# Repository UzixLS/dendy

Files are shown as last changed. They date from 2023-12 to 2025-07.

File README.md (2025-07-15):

## Dendy
Yet another Dendy (Famicom) clone - 8-bit home video game console

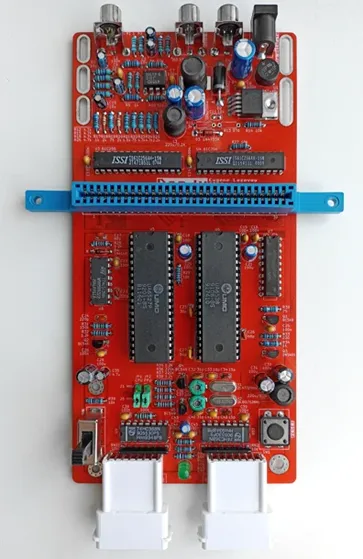
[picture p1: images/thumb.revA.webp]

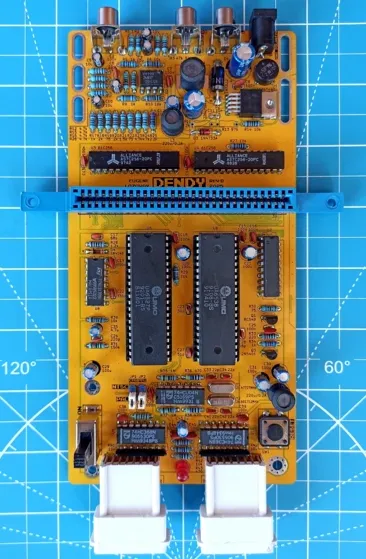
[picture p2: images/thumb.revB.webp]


[(more random photos there)](https://cloud.err200.net/index.php/s/73TR85tYZkMm8Ax?path=%2Fdendy)

- PCB optimized for NewGame's case
- Almost all components is DIP (THT)
- 9-12V DC power supply with any polarity
- Step-down switching regulator
- PNP+NPN transistors-based video amplifier
- OpAmp-based audio mixer/amplifier
- Two switchable quartz crystals (PAL+NTSC)

### Changelog & current status
* Rev.A - first release. Please note the [errata](pcb/rev.A/ERRATA.txt)
* Rev.B:
    - Reworked crystal generator circuit
    - Tuned pcb's dimensions and holes placement for better compatibility with enclosures
    - Various minor changes and improvements
* Rev.B1:
    - Power switch moved up to 0.5mm
    - Various minor changes and improvements

### Credits
I want to express my appreciation to the
 - megawalkman
 - HardWareMan
 - lm2000
 - HotPixel

authors of the following projects, which served as inspiration and as reference for my development:

- https://www.emu-land.net/forum/index.php/topic,75737.0.html - Dendy Classic/Junior Steepler Remake
- https://www.emu-land.net/forum/index.php/topic,78815.0.html - Dendy Junior Remastered
- https://github.com/mleonid2000/dendy_junior_remastered - Dendy Junior Remastered
- https://github.com/HotPixelChannel/Candy_8bit - Candy 8bit system

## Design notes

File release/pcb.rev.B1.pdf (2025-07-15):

1 | 2 | 3 | 4 | 5 | 6 | 7 | 8
1 | 2 | 3 | 4 | 5 | 6 | 7 | 8

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
F Date: 2025-06-08 KiCad | E.D.A. 8.0.9 Size: A3 | Rev: | B1

# Id: 1/1 Title: Dendy

File: dendy.kicad_sch Sheet: / Eugene | Lozovoy Based | on original | Famicom, | HardWareMan, megawalkman, | lm2000, | HotPixel schematics Famicom/NES | clone

GND

+5V

+5VA_1 | R1

1

C30

100u | C29
| 100u

1

- 2 +
3 | V⁻ 4 V⁺ 8 | U2A
4558D GNDA | R2

1 Y1
21.47727MHz | C1
10u | GNDA R3 47k

+5V

13 | 12 U11F
74HCU04 | GNDA
O2 | 10 O1 | 11 O0 | 12 A1 13 | A0 14 | E
15 | O3 | 9 U8B
74LS139 | R36 470 GND 14 VCC ²⁸ A14 1 | A0 10 | Q0 11 Q1 12 Q2 13 Q3 15 Q4 16 Q5 17 Q6 18 Q7 19 A12 2 | ~{CS}20 A10 21 | ~{OE}22 A11 23 A9 24 A8 25 A13 26 | ~{WE}27 A7 3 | A6 4 | A5 5 | A4 6 | A3 7 | A2 8 | A1 9 | U3

# 61C256 SRAM

6264, 62128, | 62256, | AS7C256, W24257AK

R7 510

GND GND

11 | 10 U11E

74HCU04 GND

GND | GND 14 VCC ²⁸ A14 1 | A0 10 | Q0 11 Q1 12 Q2 13 Q3 15 Q4 16 Q5 17 Q6 18 Q7 19 A12 2 | ~{CS}20 A10 21 | ~{OE}22 A11 23 A9 24 A8 25 A13 26 | ~{WE}27 A7 3 | A6 4 | A5 5 | A4 6 | A3 7 | A2 8 | A1 9 | U4

# 61C256 SRAM

6264, 62128, | 62256, | AS7C256

R14
10k 1
2

3

SW2

R27 10k

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
100n

GND

C24

220p ¹
2

3

JP1

GND

1

2

3

J4 DC IN

GND | VCC ¹⁶ GND

8 U8C
74LS139

GND

GND

GND GND

C16

100n | C15

100n C14

100n

+5V | GND GND

C19

100n

-1

2 +

3

4 D1

+5V

1

2

J1RCJ-014

C22

330p | 1

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
J5 FC 60 pin cartridge | slot +5V
F1 | 1A
OE 1 | GND 10
LE 11 | O4 12 D4 13 D5 14 | O5 15 O6 16 D6 17 D7 18 | O7 19 O0 | 2 VCC ²⁰ D0 3 | D1 4 | O1 | 5 O2 | 6 D2 7 | D3 8 | O3 | 9 U7
74LS373 GND

+5V R28

1.2k D4

1N4148 | GND

C4

470u/25V

+5V C23

30p | C17
68p | C26

68p GND GND

R29 | 10k GND
+5V | GND GND GND | SND1 | 1 A6 10 A7 11 A8 12 A9 13 A10 14 A11 15 A12 16 A13 17 A14 18 A15 19 SND2 | 2 GND 20 D7 21 D6 22 D5 23 D4 24 D3 25 D2 26 D1 27 D0 28 CLK 29 ~{RST} 3 | TST 30 | M2 31 ~{IRQ} 32 ~{NMI} 33 | R/~{W} 34 ~{OE2} 35 ~{OE1} 36 OUT2 37 OUT1 38 OUT0 39 | A0 | 4 VCC ⁴⁰ | A1 | 5 A2 | 6 A3 | 7 A4 | 8 A5 | 9 U5 UA6527P CPU
HA6527P, TA-03NP, | MG-P-501 | +5V GND R¹¹ 3kL1 | C11

10n 1

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
J9 DB15_Male

Joypad 2 ¹⁰k R⁴² 10k R⁴¹ C43

1u GND

R/~{W} 1 | A2 10 A1 11 A0 12 ~{CS} 13 EXT0 14 EXT1 15 EXT2 16 EXT3 17 CLK 18 ~{INT} 19 D0 2 | GND 20 | VOUT 21 ~{RST} 22 | ~{WR}23 ~{RD}24 PA13 25 PA12 26 PA11 27 PA10 28 PA9 29 D1 3 | PA8 30 ALE 39 D2 4 | VCC ⁴⁰ D3 5 | D4 6 | D5 7 | D6 8 | D7 9 | PAD7 31 PAD6 32 PAD5 33 PAD4 34 PAD3 35 PAD2 36 PAD1 37 PAD0 38 U6 UA6538 PPU
HA6538, TA-02NP, | MG-P-502

+5V

+5V | 1
2
3
4
5
6

J7

Joypad 2 GND GND

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
J8 DB15_Male

# Joypad 1 1

2
3
4
5

J6

Joypad 1 | C34
22p | R35
1M

+5V

1

2

J2RCJ-014 GNDA | GNDA GND
+5V | 1

2

J3RCJ-014 C42

22p

+5V 1

8

7

6

5

4

3

2 RN1
10k

+5VA_1 R40

100k OEa | 1
I4 | 10 O5b 11 | I5 | 12 O6b 13 | I6 | 14 OEb | 15 VCC ¹⁶
I1 | 2 O1a 3
I2 | 4 O2a 5
I3 | 6 O3a 7 | GND

# 8 O4a 9 U9

74HC368 | 1

8

7

6

5

4

3

2 RN2

# 10k GND

+5V

C44

100n +5V

L2

47uH/2A | R¹³ 1k | C9
| | 220u/16V

L3

220u/0.2A | GNDA C12
100u | C7
100n | GNDA D3
1N4733A GND OEa | 1
I4 | 10 O5b 11 | I5 | 12 O6b 13 | I6 | 14 OEb | 15 VCC ¹⁶
I1 | 2 O1a 3
I2 | 4 O2a 5
I3 | 6 O3a 7 | GND

# 8 O4a 9 U10

74HC368 +5V | D2

1N5822

+5V | GND

+5V

C3
10u R4 47k

+5VA_1R8 510

GND

JP3 | C45
100n | R6

10k +5VA_1 R12 4.7k

C31

100u | C25
100n | SW¹
GND | GND

C28

100n ¹
2
3 Q3
2N5401 VIN 1 | OUT 2 GND

## 3 FB 4 ~{ON}/OFF 5 U1

LM2596T-ADJ LM2596T-5.0 | VCC ¹⁴ GND

7 U11G

74HCU04 +5V

+5V R9
1k +5VA_2

C10

10u +5VA_1 R34 1k GNDA | GNDA

E

1 | A0 2 | A1 3 | O0 | 4 O1 | 5 O2 | 6 O3 | 7 U8A
74LS139

GNDA

+5V

L4

220u/0.2A

# R26 4.7k R16 4.7k C5

10u 3 | 4 U11B

74HCU04 Y2

26.601712MHz | R5
1k GNDA R15 4.7k | HOLE8 HOLE6 1 | 2 U11A

74HCU04 R38 470

HOLE7 C35

4.7u GND

R39 10k

R37
1M

C33

22p GND

HOLE3 HOLE5 HOLE1 C41

22p | +5V GND

D5
LED
9 | 8 U11D
74HCU04 5 | 6 U11C
74HCU04 GND | R⁴³ 470
+5V | GND GND
+5VA_2 R33 270 | 1

2
3 Q1 BC549BR30
75 | GND
R25 2.2k 75R22 GND | 75R19 R31 150k | GNDA | GND

HOLE2 HOLE4 R24
4.7k C20

100u C21

100u

R18

2k R21
1.5k C38
100n | C39
| 100n

R17
1k R23

4.7k R20
2k | C6

10u C13

100n C18

100n

R10
10k C2

100n +

5

- 6

7 U2B
4558D

+5V

A13D7 D6 A12D5 M2 A14 PAD5 PAD1 | PAD7 PA13 PAD6 ~{PWR} | A0A1VA10 ~{PRD} | D1 D2 D4 D3 D0 ~{PRD} VOUT

# ~{PWR} PA13 PA12 PA11 PPUCLK

SND_O

SND2

A10 A8 PAD2 PAD7 ~{VRAMCS} PAD0 | ~{IRQ} ~{PRD} | A2A4A7A3A5

D2

~{PPUSEL} | A2~{NMI} PPUCLK
~{PPUSEL} R/~{W} M2 | ~{ROMSEL} A14 | ~{RAMSEL} A6 | ~{RAMSEL} A2 | J1CLK | J1D¹ | J1D⁰ A10 | D7

J1D1

# J1D0M2 PA13

D6 J2D⁰ | OUT2 OUT1 | OUT0 | A13

~{OE1}

R/~{W}

J2D4

J2D1

J2D3M2

D0 J2CLK ~{IRQ} | J2D⁴ | J2D² J2D¹ | D1 D3 D4 D5 | PAD6 PAD3 PAD5

J1CLK

PA8 A1 D0

J2D2
J2D0 ~{OE2}

A7

D1 D2 D3 D4

A0

# D1 D0 NPA13 D0

A1 D1

SND_I | J2CLK
D2 | A15 | D0 OUT1 OUT2 OUT0 D4 | A4 D5 D7 D6 D2 D3 | SND2 SND1 R/~{W} M2A9 | A0 A6 | A8 A8A7 A10 | A5A9A3 A5A3 | A4 A2 CPUCLK
~{NMI} ~{OE2} ~{RESET} ~{IRQ} ~{OE1} | A11 A15 A14 A13 A12 | PA10 | PA5 | PA9 PAD5 PAD1 PAD2 | PAD3 PAD2 PAD1 | PAD4 R/~{W} PA1 PA4 | ~{VRAMCS} D3 D4 D6 D5A0D7 D1 D2A1
~{RESET} J2D³ | OUT2 OUT0

J1D0

J1D0

J2CLK

J1CLK

J2MIC

J1CLK

J2D0 | J2CLK OUT0 OUT0

J1D1 OUT0

# J2D4 ~{IRQ} J2D3

J2MIC

PA8 PA6

OUT1

J2D1 | J2D0

## PA3 PA5

J2D2
J1CLK | COMPOSITE

## PA0 PA2

VOUT

CPUCLK

VA10 PA7 CLK21 | SND1 CLK26 | SND_L PA1 PAD3 PA0 PAD2 PAD0 | SND_R
PA2 PA1 PA0 PA3 PAD6 PAD7 PA9 | PAD4 PAD4 | PAD7 | PA6 PA7 PA4 PAD0 | PAD0 | ~{PWR} SND_O
~{ROMSEL} SND_I PA2 PA6 PA5 PA4 PA3 | PA9 PA11 PA7 PA12 PA8 PA10 NPA13 A11 PAD6 | A6A9 PAD3 PAD1 PAD5 PAD4
https://forums.nesdev.org/viewtopic.php?t=18877 | (pt. 6) CLOCK

https://www.emu-land.net/forum/index.php?topic=86880.0

https://www.emu-land.net/forum/index.php?topic=88313.0 NTSC CPU have þÿ÷12divider and require 21 MHz clock. PAL CPU have þÿ÷16divider and require | 26 MHz clock. Dendy CPU have þÿ÷15divider and require 26 MHz clock. Earlier UA6527P revision | have þÿ÷16divider and glitchy | in some games. Later revision | have þÿ÷15divider and works perfectly.
It should be possible | to get earlier | ones working properly | using
28.636 | MHz clock for CPU and 26 MHz clock for PPU, but I didn't | tested this. https://www.nesdev.org/wiki/PPU_variants
install | one of L1 or L2

þÿ3k©
0.08V - 2.2V | AUDIO

https://www.nesdev.org/wiki/CPU_variants POWER

For LM2596-5.0: R11 - 0 Ohm

R13,C11 - do not install

# JOYSTICKS

J2MIC circuit | has been copied from
original | FC schematic | mostly | as is
https://www.emu-land.net/forum/index.php/topic,83552.msg1475251.html#msg1475251 Certain new china's | cartridges | won't work correctly | with this
schematic | due to improper | handling | of the ~{PRD}signal in these cartridges. Thus, schematic | workarround | is required
(but it may impact | compatibility | with older carts, do this at your own risk). More info: http://www.vgdiy.com/bbs/forum.php?mod=viewthread&tid=2230 VIDEO

+5V R14

10k GND

GND 10k R⁴² 10k R⁴¹ C43

1u GND | GND

+5V

+5V RN1
10k ¹

8

7

6

5

4

3

2 U9

74HC368 OEa | 1
I4 | 10 O5b 11 | I5 | 12 O6b 13 | I6 | 14 OEb | 15 VCC ¹⁶
I1 | 2 O1a 3
I2 | 4 O2a 5
I3 | 6 O3a 7 | GND

# 8 O4a 9 GND

C44

# 100n +5V U10

74HC368 OEa | 1
I4 | 10 O5b 11 | I5 | 12 O6b 13 | I6 | 14 OEb | 15 VCC ¹⁶
I1 | 2 O1a 3
I2 | 4 O2a 5
I3 | 6 O3a 7 | GND
8 O4a 9

+5V GND

JP3 | C45
100n | C31
100u | C25

100n +5V

L4

220u/0.2A

U11B
74HCU04 3 | 4

Y2

26.601712MHz | U11A
74HCU04 1 | 2 R38 470 C33

22p GND

C41

22p GND

U11D
74HCU04 9 | 8 GND

+5V Q1 BC549B ¹

2

3R30

75 | R25 2.2k 75R22 GND | 75R19 R31 150k | GNDA C20

100u C21

100u | C38
100n | C39
100n | C13

100n C18

100n +5V | +5V C30
100u | C29
| 100u

Y1

21.47727MHz | U11F
74HCU04 13 | 12 R36 470 U11E
74HCU04 11 | 10 | U8C

74LS139 VCC ¹⁶ GND

# 8 GND

C16

100n | C15

100n C14

100n | C19
| 100n

GND

+5V GND

R29 10k C17

68p C23

30p | +5V C22
330p +5V | GND GND GND GND | GND

U3

# 61C256 SRAM

6264, 62128, | 62256, | AS7C256, W24257AK GND 14 VCC ²⁸ A14 1 | A0 10 | Q0 11 Q1 12 Q2 13 Q3 15 Q4 16 Q5 17 Q6 18 Q7 19 A12 2 | ~{CS}20 A10 21 | ~{OE}22 A11 23 A9 24 A8 25 A13 26 | ~{WE}27 A7 3 | A6 4 | A5 5 | A4 6 | A3 7 | A2 8 | A1 9 | U8A
74LS139 E
1 | A0 2 | A1 3 | O0 | 4 O1 | 5 O2 | 6 O3 | 7 GND
+5V | +5V | +5V U6 UA6538 PPU
HA6538, TA-02NP, | MG-P-502 R/~{W} 1 | A2 10 A1 11 A0 12 ~{CS} 13 EXT0 14 EXT1 15 EXT2 16 EXT3 17 CLK 18 ~{INT} 19 D0 2 | GND 20 | VOUT 21 ~{RST} 22 | ~{WR}23 ~{RD}24 PA13 25 PA12 26 PA11 27 PA10 28 PA9 29 D1 3 | PA8 30 ALE 39 D2 4 | VCC ⁴⁰ D3 5 | D4 6 | D5 7 | D6 8 | D7 9 | PAD7 31 PAD6 32 PAD5 33 PAD4 34 PAD3 35 PAD2 36 PAD1 37 PAD0 38 GND

+5V U5 UA6527P CPU
HA6527P, TA-03NP, | MG-P-501 SND1 | 1 A6 10 A7 11 A8 12 A9 13 A10 14 A11 15 A12 16 A13 17 A14 18 A15 19 SND2 | 2 GND 20 D7 21 D6 22 D5 23 D4 24 D3 25 D2 26 D1 27 D0 28 CLK 29 ~{RST} 3 | TST 30 | M2 31 ~{IRQ} 32 ~{NMI} 33 | R/~{W} 34 ~{OE2} 35 ~{OE1} 36 OUT2 37 OUT1 38 OUT0 39 | A0 | 4 VCC ⁴⁰ | A1 | 5 A2 | 6 A3 | 7 A4 | 8 A5 | 9 GND | GND | GND

C26

68p | GND

# +5V GND

U7
74LS373 OE 1 | GND 10
LE 11 | O4 12 D4 13 D5 14 | O5 15 O6 16 D6 17 D7 18 | O7 19 O0 | 2 VCC ²⁰ D0 3 | D1 4 | O1 | 5 O2 | 6 D2 7 | D3 8 | O3 | 9

+5V

J5 FC 60 pin cartridge slot 1

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
# 9 GND GND

+5V GND | GND GND GND

+5V

+5V | R27 10k U4

# 61C256 SRAM

6264, 62128, | 62256, | AS7C256 GND 14 VCC ²⁸ A14 1 | A0 10 | Q0 11 Q1 12 Q2 13 Q3 15 Q4 16 Q5 17 Q6 18 Q7 19 A12 2 | ~{CS}20 A10 21 | ~{OE}22 A11 23 A9 24 A8 25 A13 26 | ~{WE}27 A7 3 | A6 4 | A5 5 | A4 6 | A3 7 | A2 8 | A1 9

GND

R7 510 GNDA

+5V

+5V | U11G

74HCU04 VCC ¹⁴ GND

# 7 R12 4.7k +5VA_1 R6

10k R8 510 +5VA_1 | R4 47k

J3RCJ-014 1

# 2 GNDA GNDA

J2RCJ-014 1

2 GNDA R3 47k GNDA GNDA U2A 4558D

1

- 2 +
3 | V⁻ 4 V⁺ 8

# +5VA_1 C2

100n R10
10k C6

10u R20
2k R23
4.7k R17
1k R21

1.5k R18

2k R24

4.7k | GND R⁴³ 470 | D5

LED

+5V R39 10k R15 4.7k GNDA | R5

1k C5

# 10uR16 4.7k R26 4.7k GNDA

+5VA_1 C10

10u | R9

1k U1

LM2596T-ADJ LM2596T-5.0 VIN 1 | OUT 2 GND

## 3 FB 4 ~{ON}/OFF 5 C28

100n GND | GND

D2

1N5822 | D3
1N4733A | C7

100n C12

100u

L3

220u/0.2A C9

220u/16V

L2

47uH/2A

C42

22p C34

22p

J6
Joypad 1 1

2
3
4
5

J8 DB15_Male

Joypad 1 1

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
# 9 GND GND

J7
Joypad 2 1

2
3
4
5
6
+5V

+5V

J9 DB15_Male

Joypad 2 1

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
9 C11

10n

L1

1 | 2 | 3 | 4

A

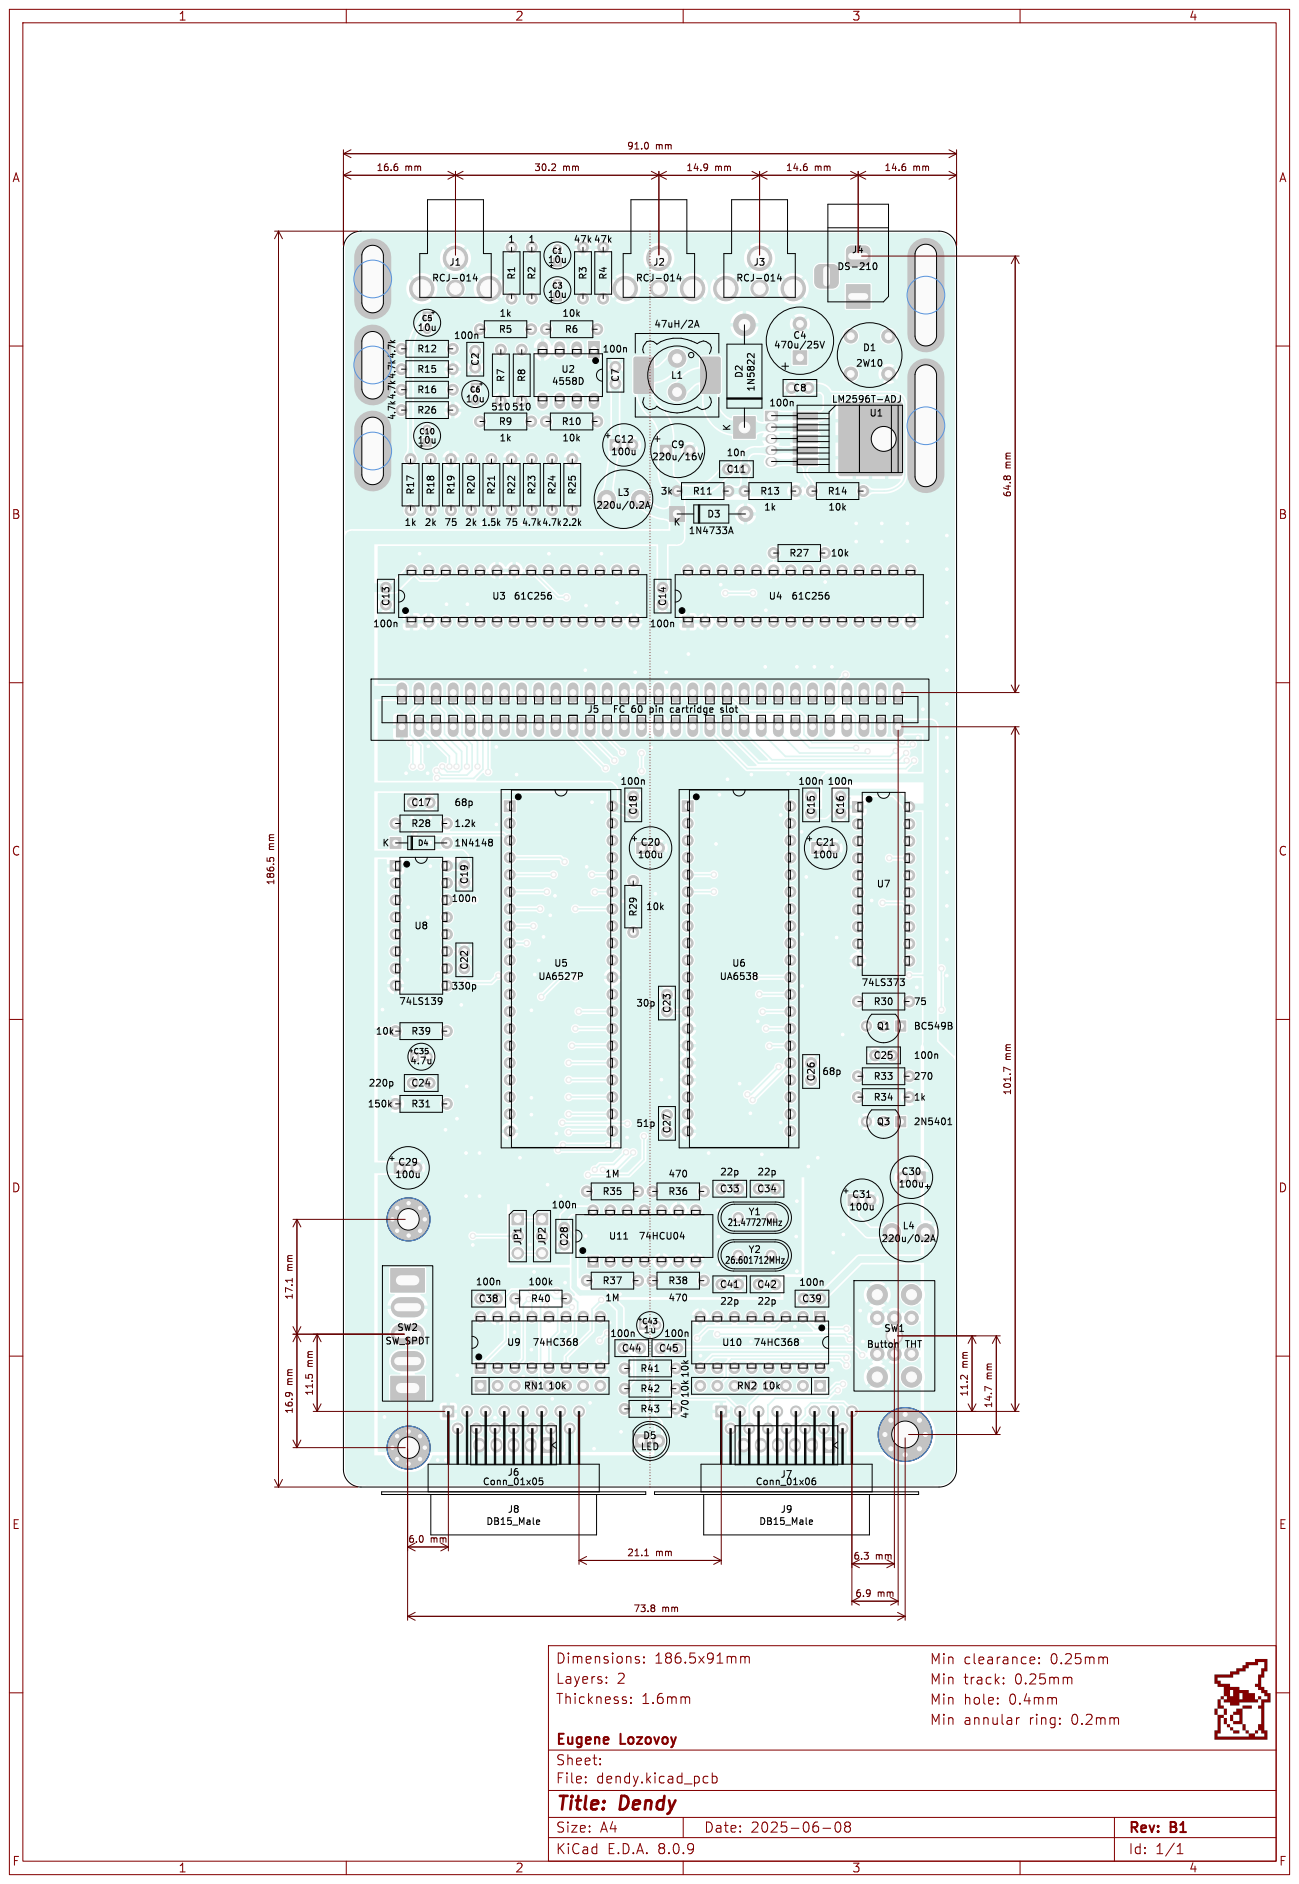
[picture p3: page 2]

1 | 2 | 3 | 4

A

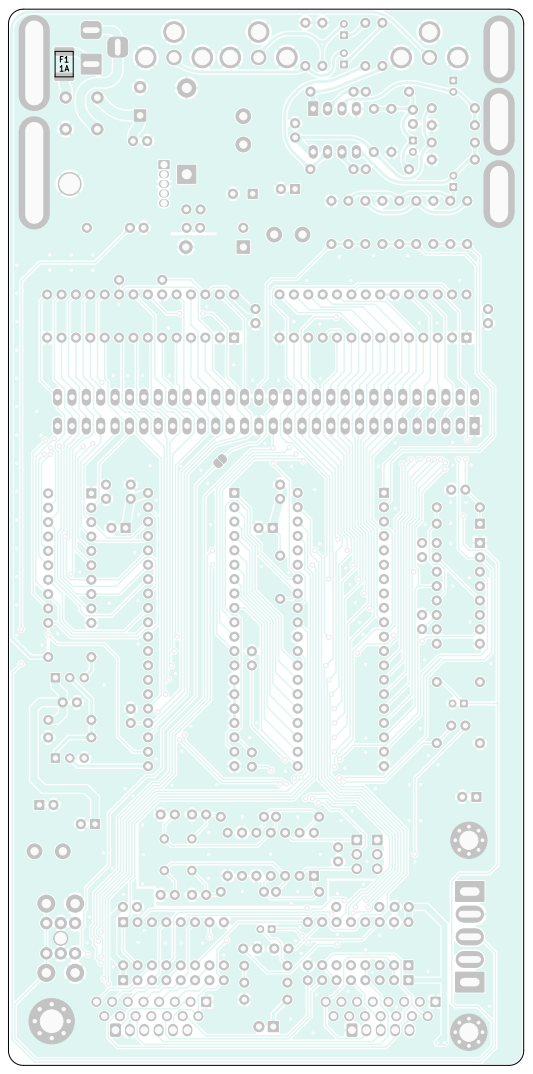
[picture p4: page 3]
F Date: 2025-06-08 KiCad; E.D.A. 8.0.9 Size: A4; Rev:; File: dendy.kicad_pcb Sheet: Eugene; Lozovoy Thickness: 1.6mm; Layers: 2 Dimensions:; Min clearance:

Min track: 0.25mm
Min hole: 0.4mm
Min annular ring: 0.2mm

Id: 1/1 Title: Dendy

# Bill Of Materials

References | | | Value | Footprint | Qty
C1 C3 C5 C6 C10 | 10u | PCM_Capacitor_THT_AKL:CP_Radial_D4.0 mm_P2.00mm | 5
C2 C7 C8 C13 C14 C15 C16 C18 C19 C25 C28 C38 C39 C44 C45 | 100n | PCM_Capacitor_THT_AKL:C_Disc_D5.0mm _W2.5mm_P2.50mm | 15
C4 | 470u/25V | PCM_Capacitor_THT_AKL:CP_Radial_D10. 0mm_P5.00mm | 1
C9 | 220u/16V | PCM_Capacitor_THT_AKL:CP_Radial_D8.0 mm_P3.50mm | 1
C11 | 10n | PCM_Capacitor_THT_AKL:C_Disc_D5.0mm _W2.5mm_P2.50mm | 1
C12 C20 C21 C29 C30 C31 | 100u | PCM_Capacitor_THT_AKL:CP_Radial_D6.3 mm_P2.50mm | 6
C17 C26 | 68p | PCM_Capacitor_THT_AKL:C_Disc_D5.0mm _W2.5mm_P2.50mm | 2
C22 | 330p | PCM_Capacitor_THT_AKL:C_Disc_D5.0mm _W2.5mm_P2.50mm | 1
C23 | 30p | PCM_Capacitor_THT_AKL:C_Disc_D5.0mm _W2.5mm_P2.50mm | 1
C24 | 220p | PCM_Capacitor_THT_AKL:C_Disc_D5.0mm _W2.5mm_P2.50mm | 1
C27 | 51p | PCM_Capacitor_THT_AKL:C_Disc_D5.0mm _W2.5mm_P2.50mm | 1
C33 C34 C41 C42 | 22p | PCM_Capacitor_THT_AKL:C_Disc_D5.0mm _W2.5mm_P2.50mm | 4
C35 | 4.7u | PCM_Capacitor_THT_AKL:CP_Radial_D4.0 mm_P2.00mm | 1
C43 | 1u | PCM_Capacitor_THT_AKL:CP_Radial_D4.0 mm_P2.00mm | 1
D1 | 2W10 | my:Diode_Bridge_Round_D10.0mm | 1
D2 | 1N5822 | PCM_Diode_THT_AKL:D_DO-201AD_P15.2 4mm_Horizontal | 1
D3 | 1N4733A | PCM_Diode_THT_AKL:D_DO-41_SOD81_P 10.16mm_Horizontal | 1
D4 | 1N4148 | Diode_THT:D_DO-35_SOD27_P7.62mm_Ho rizontal | 1
D5 | LED | LED_THT:LED_D5.0mm | 1
F1 | 1A | Fuse:Fuse_1812_4532Metric_Pad1.30x3.40 mm_HandSolder | 1
J1 J2 J3 | RCJ-014 | my:CUI_RCJ-01X | 3
J4 | DS-210 | Connector_BarrelJack:BarrelJack_Horizontal | 1
J5 | FC 60 pin cartridge slot | my:FC60 | 1
J8 J9 | DB15_Male | Connector_Dsub:DSUB-15_Male_Horizontal _P2.77x2.54mm_EdgePinOffset9.40mm | 2
JP1 JP2 | Jumper_3_Bridged12 | Connector_PinHeader_2.54mm:PinHeader_1 x03_P2.54mm_Vertical | 2
L1 | 47uH/2A | PCM_Inductor_SMD_AKL:L_12x12mm_H8m m | 1

# dendy rev.B1 BOM page 1/3

L3 L4 | 220u/0.2A | PCM_Inductor_THT_AKL:L_Radial_D8.7mm _P5.00mm_Fastron_07HCP | 2
Q1 | BC549B | PCM_Package_TO_SOT_THT_AKL:TO-92_I nline_Wide_CBE | 1
Q3 | 2N5401 | PCM_Package_TO_SOT_THT_AKL:TO-92_I nline_Wide_EBC | 1
R1 R2 | 1 | PCM_Resistor_THT_AKL:R_Axial_DIN0207_ L6.3mm_D2.5mm_P7.62mm_Horizontal | 2
R3 R4 | 47k | PCM_Resistor_THT_AKL:R_Axial_DIN0207_ L6.3mm_D2.5mm_P7.62mm_Horizontal | 2
R5 R9 R13 R17 R34 | 1k | PCM_Resistor_THT_AKL:R_Axial_DIN0207_ L6.3mm_D2.5mm_P7.62mm_Horizontal | 5
R6 R10 R14 R27 R29 R39 R41 R42 | 10k | PCM_Resistor_THT_AKL:R_Axial_DIN0207_ L6.3mm_D2.5mm_P7.62mm_Horizontal | 8
R7 R8 | 510 | PCM_Resistor_THT_AKL:R_Axial_DIN0207_ L6.3mm_D2.5mm_P7.62mm_Horizontal | 2
R11 | 3k | PCM_Resistor_THT_AKL:R_Axial_DIN0207_ L6.3mm_D2.5mm_P7.62mm_Horizontal | 1
R12 R15 R16 R23 R24 R26 | 4.7k | PCM_Resistor_THT_AKL:R_Axial_DIN0207_ L6.3mm_D2.5mm_P7.62mm_Horizontal | 6
R18 R20 | 2k | PCM_Resistor_THT_AKL:R_Axial_DIN0207_ L6.3mm_D2.5mm_P7.62mm_Horizontal | 2
R19 R22 R30 | 75 | PCM_Resistor_THT_AKL:R_Axial_DIN0207_ L6.3mm_D2.5mm_P7.62mm_Horizontal | 3
R21 | 1.5k | PCM_Resistor_THT_AKL:R_Axial_DIN0207_ L6.3mm_D2.5mm_P7.62mm_Horizontal | 1
R25 | 2.2k | PCM_Resistor_THT_AKL:R_Axial_DIN0207_ L6.3mm_D2.5mm_P7.62mm_Horizontal | 1
R28 | 1.2k | PCM_Resistor_THT_AKL:R_Axial_DIN0207_ L6.3mm_D2.5mm_P7.62mm_Horizontal | 1
R31 | 150k | PCM_Resistor_THT_AKL:R_Axial_DIN0207_ L6.3mm_D2.5mm_P7.62mm_Horizontal | 1
R33 | 270 | PCM_Resistor_THT_AKL:R_Axial_DIN0207_ L6.3mm_D2.5mm_P7.62mm_Horizontal | 1
R35 R37 | 1M | PCM_Resistor_THT_AKL:R_Axial_DIN0207_ L6.3mm_D2.5mm_P7.62mm_Horizontal | 2
R36 R38 R43 | 470 | PCM_Resistor_THT_AKL:R_Axial_DIN0207_ L6.3mm_D2.5mm_P7.62mm_Horizontal | 3
R40 | 100k | PCM_Resistor_THT_AKL:R_Axial_DIN0207_ L6.3mm_D2.5mm_P7.62mm_Horizontal | 1
RN1 RN2 | 10k | Resistor_THT:R_Array_SIP8 | 2
SW1 | Button THT | my:FC_Reset_Switch_Universal | 1
SW2 | SW_SPDT | my:FC_Power_Switch_Universal | 1
U1 | LM2596T-ADJ (Alternatives: LM2596T-5.0) | my:TO-220-263-5_Horizontal_TabDown | 1
U2 | 4558D | PCM_Package_DIP_AKL:DIP-8_W7.62mm_ LongPads | 1
U3 U4 | 61C256 (Alternatives: 6264, 62128, 62256, AS7C256, W24257AK) | PCM_Package_DIP_AKL:DIP-28_W7.62mm | 2
U5 | UA6527P (Alternatives: HA6527P, TA-03NP, MG-P-501) | PCM_Package_DIP_AKL:DIP-40_W15.24m m_Socket | 1

# dendy rev.B1 BOM page 2/3

U6 | UA6538 (Alternatives: HA6538, TA-02NP, MG-P-502) | PCM_Package_DIP_AKL:DIP-40_W15.24m m_Socket | 1
U7 | 74LS373 | PCM_Package_DIP_AKL:DIP-20_W7.62mm | 1
U8 | 74LS139 | PCM_Package_DIP_AKL:DIP-16_W7.62mm | 1
U9 U10 | 74HC368 | PCM_Package_DIP_AKL:DIP-16_W7.62mm | 2
U11 | 74HCU04 | PCM_Package_DIP_AKL:DIP-14_W7.62mm | 1
Y1 | 21.47727MHz | PCM_Crystal_AKL:Crystal_HC49-U_Vertical | 1
Y2 | 26.601712MHz | PCM_Crystal_AKL:Crystal_HC49-U_Vertical | 1

# dendy rev.B1 BOM page 3/3

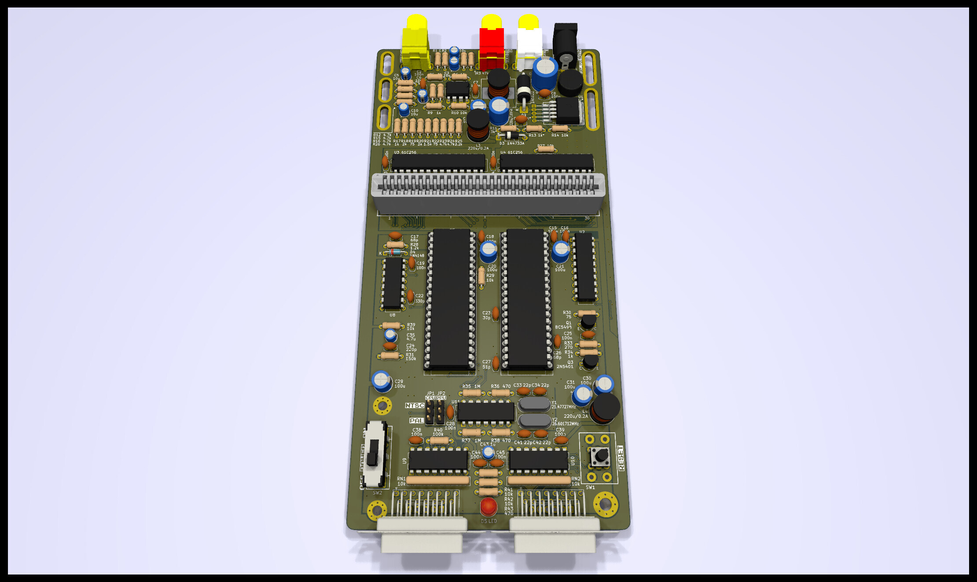
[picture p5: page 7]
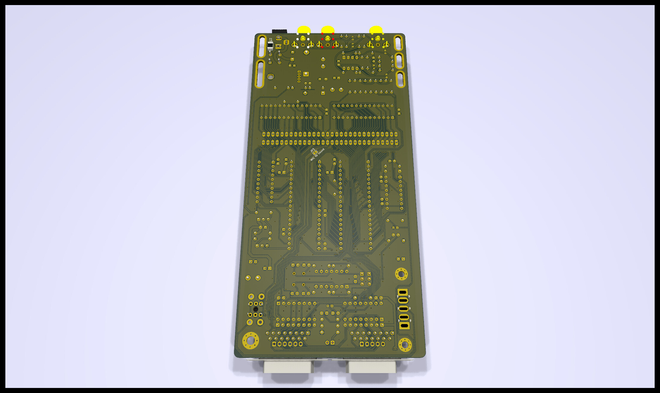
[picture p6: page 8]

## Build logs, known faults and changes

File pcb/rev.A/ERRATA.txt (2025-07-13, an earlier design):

- Incorrect Y1/Y2 generator circuit - see rev.A1 for fix

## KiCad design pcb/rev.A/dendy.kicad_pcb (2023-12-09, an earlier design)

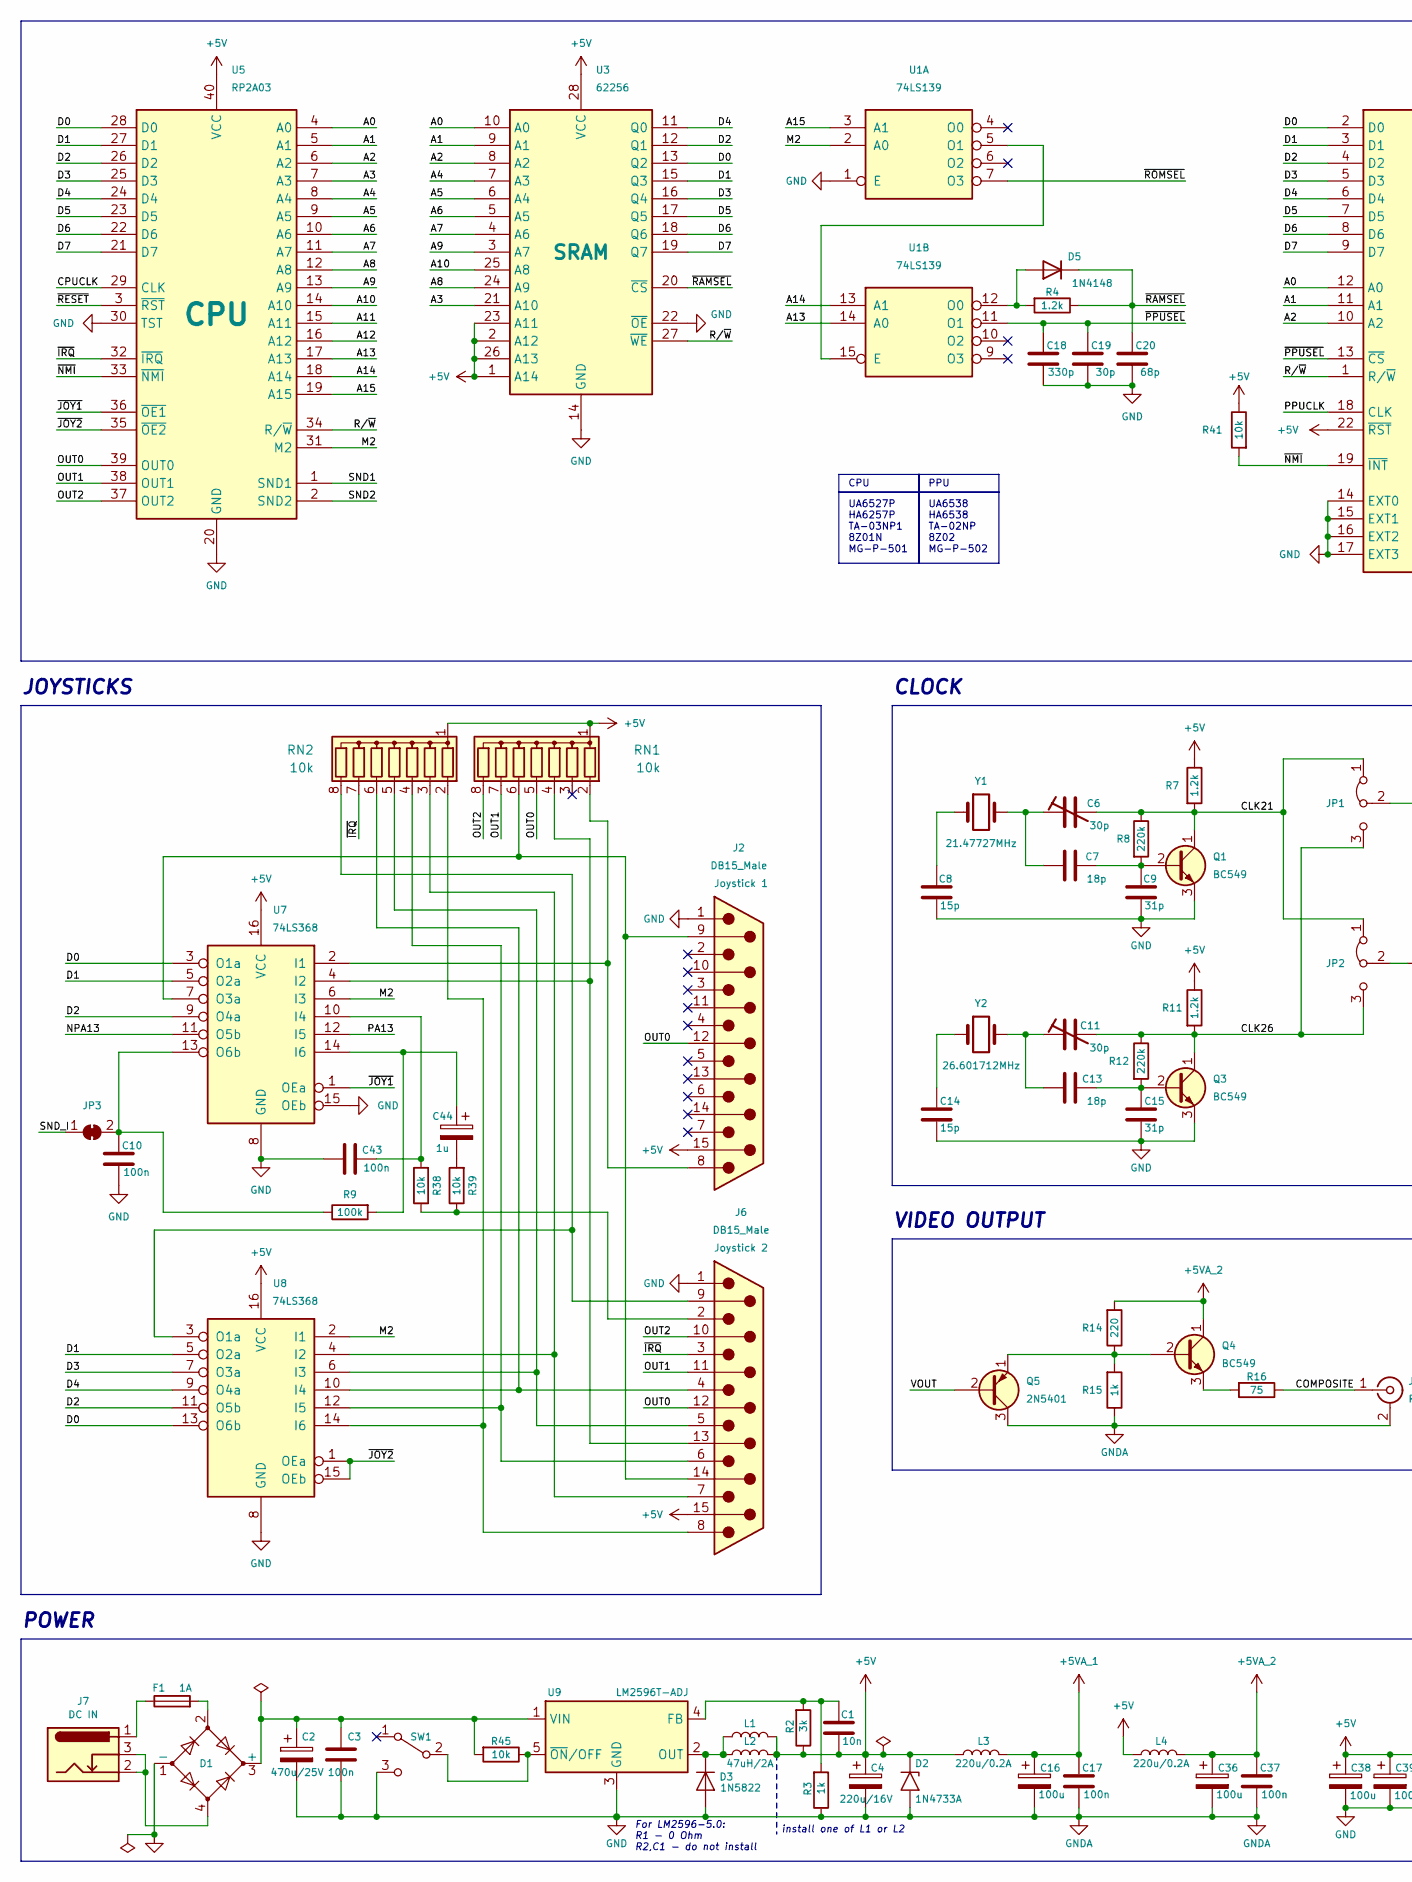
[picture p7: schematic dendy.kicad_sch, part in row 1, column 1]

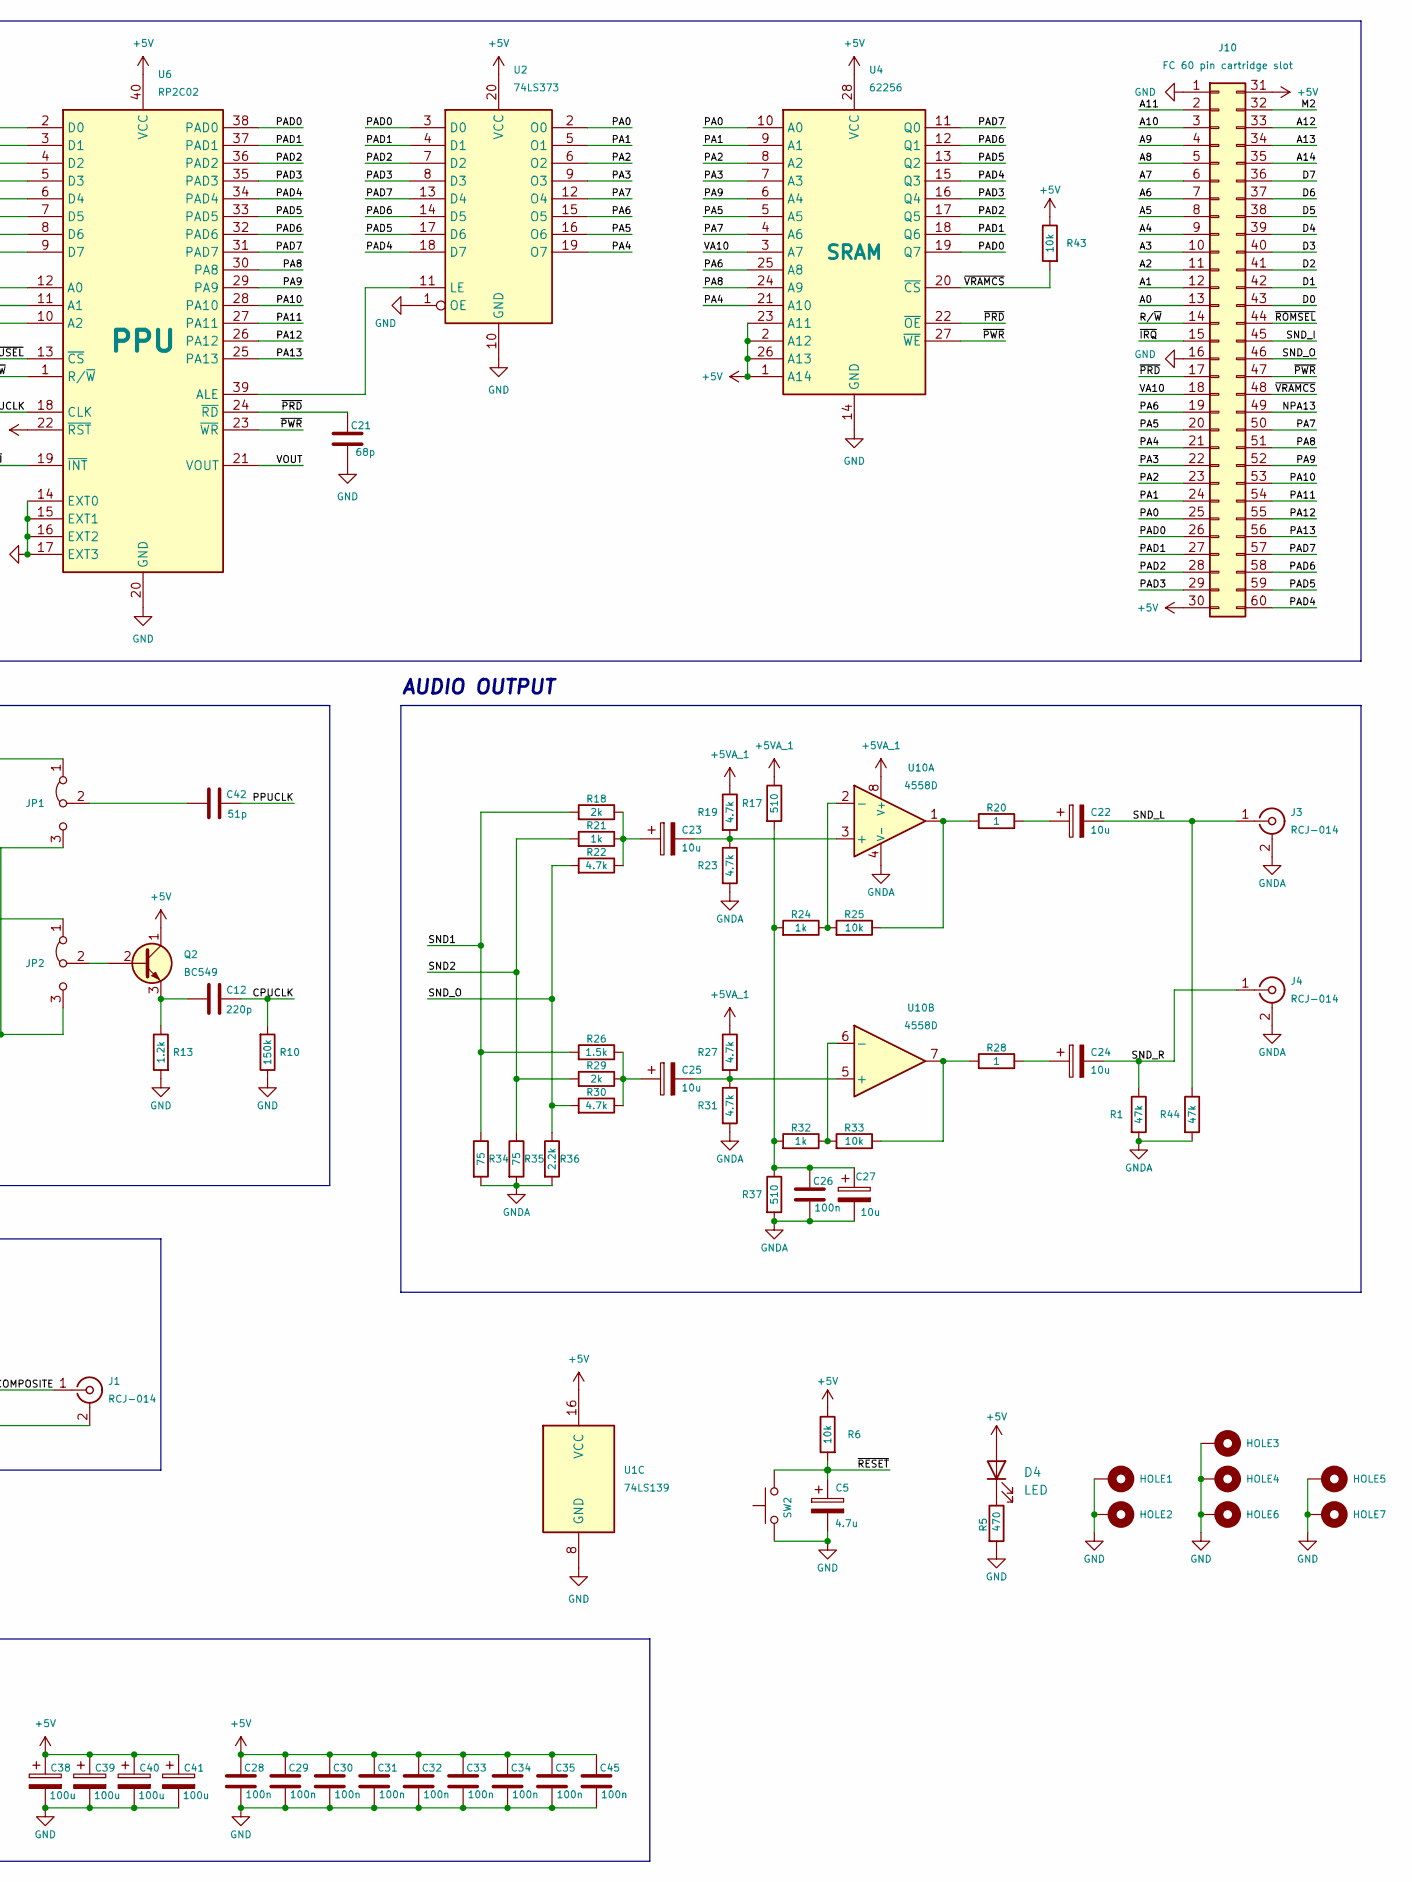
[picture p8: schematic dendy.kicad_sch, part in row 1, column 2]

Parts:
C1: 10n; C_Disc_D5.0mm_W2.5mm_P2.50mm
C2: 470u/25V; CP_Radial_D10.0mm_P5.00mm
C3, C10, C17, C26, C28, C29, C30, C31, C32, C33, C34, C35, C37, C43, C45: 100n; C_Disc_D5.0mm_W2.5mm_P2.50mm
C4: 220u/16V; CP_Radial_D8.0mm_P3.50mm
C5: 4.7u; CP_Radial_D4.0mm_P2.00mm
C6, C11: 30p; C_Trimmer_GKU_L5.6mm_W5.0mm_P5.8mm
C7, C13: 18p; C_Disc_D5.0mm_W2.5mm_P2.50mm
C8, C14: 15p; C_Disc_D5.0mm_W2.5mm_P2.50mm
C9, C15: 31p; C_Disc_D5.0mm_W2.5mm_P2.50mm
C12: 220p; C_Disc_D5.0mm_W2.5mm_P2.50mm
C16, C36, C38, C39, C40, C41: 100u; CP_Radial_D6.3mm_P2.50mm
C18: 330p; C_Disc_D5.0mm_W2.5mm_P2.50mm
C19: 30p; C_Disc_D5.0mm_W2.5mm_P2.50mm
C20, C21: 68p; C_Disc_D5.0mm_W2.5mm_P2.50mm
C22, C23, C24, C25, C27: 10u; CP_Radial_D4.0mm_P2.00mm
C42: 51p; C_Disc_D5.0mm_W2.5mm_P2.50mm
C44: 1u; CP_Radial_D4.0mm_P2.00mm
D1: 2W10; Diode_Bridge_Round_D10.0mm
D2: 1N4733A; D_DO-41_SOD81_P10.16mm_Horizontal
D3: 1N5822; D_DO-201AD_P15.24mm_Horizontal
D4: LED; LED_D5.0mm
D5: 1N4148; D_DO-35_SOD27_P7.62mm_Horizontal
F1: 1A; Fuse_1812_4532Metric_Pad1.30x3.40mm_HandSolder
HOLE1: HOLE; MountingHole_3.2mm_M3_Pad_Via
HOLE2: HOLE; MountingHole_4mm_Pad_Via
HOLE3, HOLE4, HOLE5, HOLE6, HOLE7: HOLE; MountingHole_3.2mm_M3_DIN965_Pad
J1, J3, J4: RCJ-014; CUI_RCJ-01X
J2, J6: DB15_Male; DSUB-15_Male_Horizontal_P2.77x2.54mm_EdgePinOffset9.40mm
J7: DS-210; BarrelJack_Horizontal
J10: FC 60 pin cartridge slot; FC60
JP1, JP2: Jumper_3_Bridged12; PinHeader_1x03_P2.54mm_Vertical
JP3: SolderJumper_2_Bridged; SolderJumper-2_P1.3mm_Bridged_RoundedPad1.0x1.5mm
L1: 47uH/2A; L_12x12mm_H8mm
L2: 47uH/2A; L_Radial_D8.7mm_P5.00mm_Fastron_07HCP
L3, L4: 220u/0.2A; L_Radial_D8.7mm_P5.00mm_Fastron_07HCP
Q1, Q2, Q3, Q4: BC549; TO-92_Inline_Wide_CBE
Q5: 2N5401; TO-92_Inline_Wide_EBC
R1, R44: 47k; R_Axial_DIN0207_L6.3mm_D2.5mm_P7.62mm_Horizontal
R2: 3k; R_Axial_DIN0207_L6.3mm_D2.5mm_P7.62mm_Horizontal
R3, R15, R21, R24, R32: 1k; R_Axial_DIN0207_L6.3mm_D2.5mm_P7.62mm_Horizontal
R4, R7, R11, R13: 1.2k; R_Axial_DIN0207_L6.3mm_D2.5mm_P7.62mm_Horizontal
R5: 470; R_Axial_DIN0207_L6.3mm_D2.5mm_P7.62mm_Horizontal
R6, R25, R33, R38, R39, R41, R43, R45: 10k; R_Axial_DIN0207_L6.3mm_D2.5mm_P7.62mm_Horizontal
R8, R12: 220k; R_Axial_DIN0207_L6.3mm_D2.5mm_P7.62mm_Horizontal
R9: 100k; R_Axial_DIN0207_L6.3mm_D2.5mm_P7.62mm_Horizontal
R10: 150k; R_Axial_DIN0207_L6.3mm_D2.5mm_P7.62mm_Horizontal
R14: 220; R_Axial_DIN0207_L6.3mm_D2.5mm_P7.62mm_Horizontal
R16, R34, R35: 75; R_Axial_DIN0207_L6.3mm_D2.5mm_P7.62mm_Horizontal
R17, R37: 510; R_Axial_DIN0207_L6.3mm_D2.5mm_P7.62mm_Horizontal
R18, R29: 2k; R_Axial_DIN0207_L6.3mm_D2.5mm_P7.62mm_Horizontal
R19, R22, R23, R27, R30, R31: 4.7k; R_Axial_DIN0207_L6.3mm_D2.5mm_P7.62mm_Horizontal
R20, R28: 1; R_Axial_DIN0207_L6.3mm_D2.5mm_P7.62mm_Horizontal
R26: 1.5k; R_Axial_DIN0207_L6.3mm_D2.5mm_P7.62mm_Horizontal
R36: 2.2k; R_Axial_DIN0207_L6.3mm_D2.5mm_P7.62mm_Horizontal
RN1, RN2: 10k; R_Array_SIP8
SW1: SW_SPDT; SS12F44G5
SW2: Button THT; FC_Reset_Switch_Universal
U1: 74LS139; DIP-16_W7.62mm
U2: 74LS373; DIP-20_W7.62mm
U3, U4: 62256; DIP-28_W7.62mm
U5: RP2A03; DIP-40_W15.24mm_Socket
U6: RP2C02; DIP-40_W15.24mm_Socket
U7, U8: 74LS368; DIP-16_W7.62mm
U9: LM2596T-ADJ; TO-220-263-5_Horizontal_TabDown
U10: 4558D; DIP-8_W7.62mm_LongPads
Y1: 21.47727MHz; Crystal_HC49-U_Vertical
Y2: 26.601712MHz; Crystal_HC49-U_Vertical

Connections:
+5V: C1.1, C4.1, C28.2, C29.2, C30.2, C31.2, C32.2, C33.2, C34.2, C35.2, C38.1, C39.1, C40.1, C41.1, C45.2, D2.1 (A1), D4.2 (A), J2.15, J6.15, J10.30, J10.31, L1.2, L2.2, L3.1, L4.1, Q2.1 (C), R2.1, R6.1, R7.1, R11.1, R41.1, R43.1, RN1.1 (common), RN2.1 (common), U1.16 (VCC), U2.20 (VCC), U3.1 (A14), U3.2 (A12), U3.23 (A11), U3.26 (A13), U3.28 (VCC), U4.1 (A14), U4.2 (A12), U4.23 (A11), U4.26 (A13), U4.28 (VCC), U5.40 (VCC), U6.22 (~RST), U6.40 (VCC), U7.16 (VCC), U8.16 (VCC)
+5VA_1: C16.1, C17.2, L3.2, R17.1, R19.1, R27.1, U10.8 (V+)
+5VA_2: C36.1, C37.2, L4.2, Q4.1 (C), R14.2
/A0: J10.13, U3.10 (A0), U5.4 (A0), U6.12 (A0)
/A1: J10.12, U3.9 (A1), U5.5 (A1), U6.11 (A1)
/A2: J10.11, U3.8 (A2), U5.6 (A2), U6.10 (A2)
/A3: J10.10, U3.21 (A10), U5.7 (A3)
/A4: J10.9, U3.7 (A3), U5.8 (A4)
/A5: J10.8, U3.6 (A4), U5.9 (A5)
/A6: J10.7, U3.5 (A5), U5.10 (A6)
/A7: J10.6, U3.4 (A6), U5.11 (A7)
/A8: J10.5, U3.24 (A9), U5.12 (A8)
/A9: J10.4, U3.3 (A7), U5.13 (A9)
/A10: J10.3, U3.25 (A8), U5.14 (A10)
/A11: J10.2, U5.15 (A11)
/A12: J10.33, U5.16 (A12)
/A13: J10.34, U1.14 (A0), U5.17 (A13)
/A14: J10.35, U1.13 (A1), U5.18 (A14)
/A15: U1.3 (A1), U5.19 (A15)
/CLK21: C6.2, JP1.1 (A), JP2.1 (A), Q1.1 (C), R7.2, R8.1
/CLK26: C11.2, JP1.3 (B), JP2.3 (B), Q3.1 (C), R11.2, R12.1
/COMPOSITE: J1.1 (In), R16.1
/CPUCLK: C12.2, R10.2, U5.29 (CLK)
/D0: J10.43, U3.13 (Q2), U5.28 (D0), U6.2 (D0), U7.3 (O1a), U8.13 (O6b)
/D1: J10.42, U3.15 (Q3), U5.27 (D1), U6.3 (D1), U7.5 (O2a), U8.5 (O2a)
/D2: J10.41, U3.12 (Q1), U5.26 (D2), U6.4 (D2), U7.9 (O4a), U8.11 (O5b)
/D3: J10.40, U3.16 (Q4), U5.25 (D3), U6.5 (D3), U8.7 (O3a)
/D4: J10.39, U3.11 (Q0), U5.24 (D4), U6.6 (D4), U8.9 (O4a)
/D5: J10.38, U3.17 (Q5), U5.23 (D5), U6.7 (D5)
/D6: J10.37, U3.18 (Q6), U5.22 (D6), U6.8 (D6)
/D7: J10.36, U3.19 (Q7), U5.21 (D7), U6.9 (D7)
/M2: J10.32, U1.2 (A0), U5.31 (M2), U7.6 (I3), U8.2 (I1)
/NPA13: J10.49, U7.11 (O5b)
/OUT0: J2.12, J6.12, RN1.5 (R4), U5.39 (OUT0)
/OUT1: J6.11 (P111), RN1.7 (R6), U5.38 (OUT1)
/OUT2: J6.10, RN1.8 (R7), U5.37 (OUT2)
/PA0: J10.25, U2.2 (O0), U4.10 (A0)
/PA1: J10.24, U2.5 (O1), U4.9 (A1)
/PA2: J10.23, U2.6 (O2), U4.8 (A2)
/PA3: J10.22, U2.9 (O3), U4.7 (A3)
/PA4: J10.21, U2.19 (O7), U4.21 (A10)
/PA5: J10.20, U2.16 (O6), U4.5 (A5)
/PA6: J10.19, U2.15 (O5), U4.25 (A8)
/PA7: J10.50, U2.12 (O4), U4.4 (A6)
/PA8: J10.51, U4.24 (A9), U6.30 (PA8)
/PA9: J10.52, U4.6 (A4), U6.29 (PA9)
/PA10: J10.53, U6.28 (PA10)
/PA11: J10.54, U6.27 (PA11)
/PA12: J10.55, U6.26 (PA12)
/PA13: J10.56, U6.25 (PA13), U7.12 (I5)
/PAD0: J10.26, U2.3 (D0), U4.19 (Q7), U6.38 (PAD0)
/PAD1: J10.27, U2.4 (D1), U4.18 (Q6), U6.37 (PAD1)
/PAD2: J10.28, U2.7 (D2), U4.17 (Q5), U6.36 (PAD2)
/PAD3: J10.29, U2.8 (D3), U4.16 (Q4), U6.35 (PAD3)
/PAD4: J10.60, U2.18 (D7), U4.15 (Q3), U6.34 (PAD4)
/PAD5: J10.59, U2.17 (D6), U4.13 (Q2), U6.33 (PAD5)
/PAD6: J10.58, U2.14 (D5), U4.12 (Q1), U6.32 (PAD6)
/PAD7: J10.57, U2.13 (D4), U4.11 (Q0), U6.31 (PAD7)
/PPUCLK: C42.2, U6.18 (CLK)
/R/~W: J10.14, U3.27 (~WE), U5.34 (R/~W), U6.1 (R/~W)
/SND1: R18.2, R26.2, R34.1, U5.1 (SND1)
/SND2: R21.2, R29.2, R35.1, U5.2 (SND2)
/SND_I: J10.45, JP3.1 (A)
/SND_L: C22.2, J3.1 (In), R44.1
/SND_O: J10.46, R22.2, R30.2, R36.1
/SND_R: C24.2, J4.1 (In), R1.1
/VA10: J10.18, U4.3 (A7)
/VOUT: Q5.2 (B), U6.21 (VOUT)
/~IRQ: J6.3, J10.15, RN2.7 (R6), U5.32 (~IRQ)
/~JOY1: U5.36 (~OE1), U7.1 (OEa)
/~JOY2: U5.35 (~OE2), U8.1 (OEa), U8.15 (OEb)
/~NMI: R41.2, U5.33 (~NMI), U6.19 (~INT)
/~PPUSEL: C18.2, C19.2, U1.11 (O1), U6.13 (~CS)
/~PRD: C21.2, J10.17, U4.22 (~OE), U6.24 (~RD)
/~PWR: J10.47, U4.27 (~WE), U6.23 (~WR)
/~RAMSEL: C20.2, D5.1 (K), R4.1, U3.20 (~CS)
/~RESET: C5.1, R6.2, SW2.2, U5.3 (~RST)
/~ROMSEL: J10.44, U1.7 (O3)
/~VRAMCS: J10.48, R43.2, U4.20 (~CS)
GND: C2.2, C3.2, C4.2, C5.2, C8.1, C9.1, C10.1, C14.1, C15.1, C16.2, C17.1, C18.1, C19.1, C20.1, C21.1, C26.1, C27.2, C28.1, C29.1, C30.1, C31.1, C32.1, C33.1, C34.1, C35.1, C36.2, C37.1, C38.2, C39.2, C40.2, C41.2, C43.1, C45.1, D1.1 (-), D2.2 (A2), D3.2 (A), HOLE1.1, HOLE2.1, HOLE3.1, HOLE4.1, HOLE5.1, HOLE6.1, HOLE7.1, J1.2 (Ext), J2.1, J3.2 (Ext), J4.2 (Ext), J6.1, J10.1, J10.16, Q1.3 (E), Q3.3 (E), Q5.3 (C), R1.2, R3.1, R5.2, R10.1, R13.2, R15.1, R23.2, R31.2, R34.2, R35.2, R36.2, R37.2, R44.2, SW1.3 (C), SW2.1, U1.1 (E), U1.8 (GND), U2.1 (OE), U2.10 (GND), U3.14 (GND), U3.22 (~OE), U4.14 (GND), U5.20 (GND), U5.30 (TST), U6.14 (EXT0), U6.15 (EXT1), U6.16 (EXT2), U6.17 (EXT3), U6.20 (GND), U7.8 (GND), U7.15 (OEb), U8.8 (GND), U9.3 (GND), U10.4 (V-)
unnamed: C6.1, C7.1, Y1.2
unnamed: C8.2, Y1.1
unnamed: C11.1, C13.1, Y2.2
unnamed: C14.2, Y2.1
unnamed: C22.1, R20.1
unnamed: C23.1, R18.1, R21.1, R22.1
unnamed: C24.1, R28.1
unnamed: C25.1, R26.1, R29.1, R30.1
unnamed: C26.2, C27.1, R17.2, R24.2, R32.2, R37.1
unnamed: C44.2, R39.2
unnamed: C2.1, C3.1, D1.3 (+), R45.2, U9.1 (VIN)
unnamed: D1.2, F1.2
unnamed: D1.4, J7.2, J7.3
unnamed: D3.1 (K), L1.1, L2.1, U9.2 (OUT)
unnamed: D4.1 (K), R5.1
unnamed: D5.2 (A), R4.2, U1.12 (O0)
unnamed: F1.1, J7.1
unnamed: J2.9, J6.14, RN1.6 (R5), U7.7 (O3a)
unnamed: J6.9, RN2.8 (R7), U8.3 (O1a)
unnamed: J6.13, RN1.4 (R3), U7.4 (I2)
unnamed: J6.2, R38.1, R39.1
unnamed: C42.1, JP1.2 (C)
unnamed: JP2.2 (C), Q2.2 (B)
unnamed: C10.2, JP3.2 (B), R9.1, U7.13 (O6b)
unnamed: C7.2, C9.2, Q1.2 (B), R8.2
unnamed: C12.1, Q2.3 (E), R13.1
unnamed: C13.2, C15.2, Q3.2 (B), R12.2
unnamed: Q4.2 (B), Q5.1 (E), R14.1, R15.2
unnamed: Q4.3 (E), R16.2
unnamed: R20.2, R25.1, U10.1
unnamed: R28.2, R33.1, U10.7
unnamed: J2.8, RN1.2 (R1), U7.2 (I1)
unnamed: J6.8, RN2.2 (R1), U8.14 (I6)
unnamed: J6.7, RN2.3 (R2), U8.4 (I2)
unnamed: J6.6, RN2.4 (R3), U8.12 (I5)
unnamed: J6.5, RN2.5 (R4), U8.6 (I3)
unnamed: J6.4, RN2.6 (R5), U8.10 (I4)
unnamed: R45.1, SW1.2 (B), U9.5 (~ON/OFF)
unnamed: U1.5 (O1), U1.15 (E)
unnamed: U2.11 (LE), U6.39 (ALE)
unnamed: C43.2, R38.2, U7.10 (I4)
unnamed: C44.1, R9.2, U7.14 (I6)
unnamed: C1.2, R2.2, R3.2, U9.4 (FB)
unnamed: C23.2, R19.2, R23.1, U10.3 (+)
unnamed: R24.1, R25.2, U10.2 (-)
unnamed: C25.2, R27.2, R31.1, U10.5 (+)
unnamed: R32.1, R33.2, U10.6 (-)

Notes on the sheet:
CPU
CLOCK
install one of L1 or L2
PPU
UA6527P HA6257P TA-03NP1 8Z01N MG-P-501
UA6538 HA6538 TA-02NP 8Z02 MG-P-502
VIDEO OUTPUT
POWER
For LM2596-5.0: R1 - 0 Ohm R2,C1 - do not install
AUDIO OUTPUT
JOYSTICKS

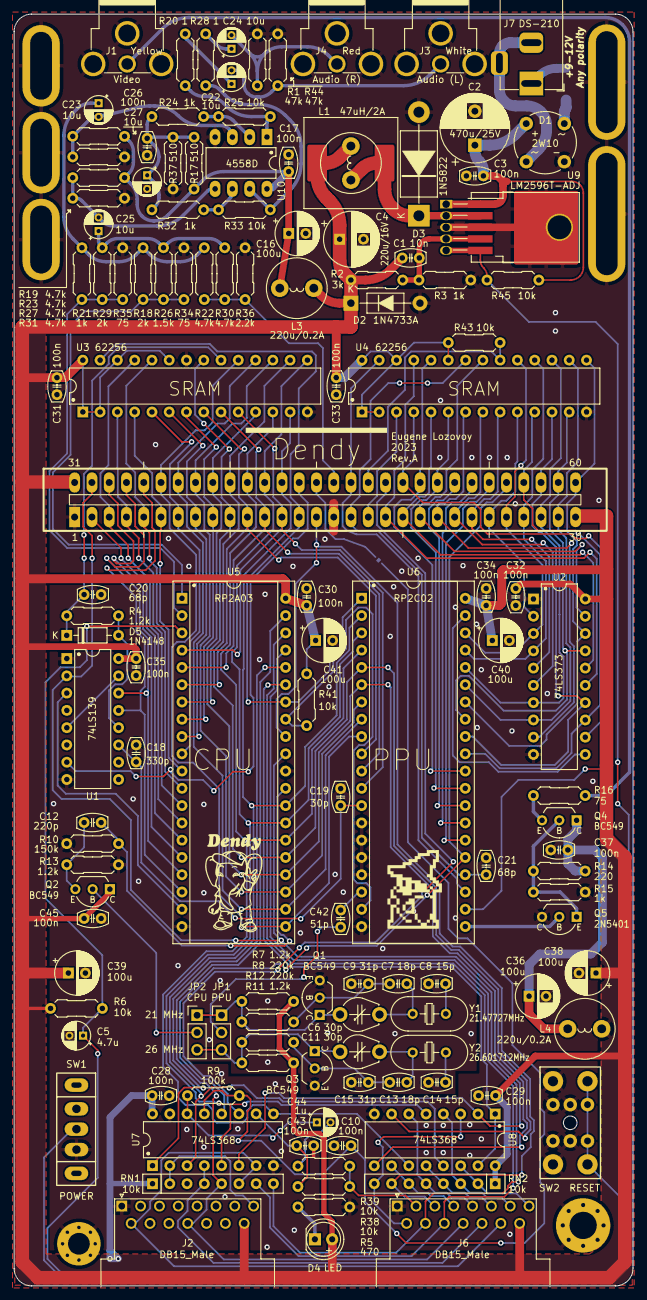
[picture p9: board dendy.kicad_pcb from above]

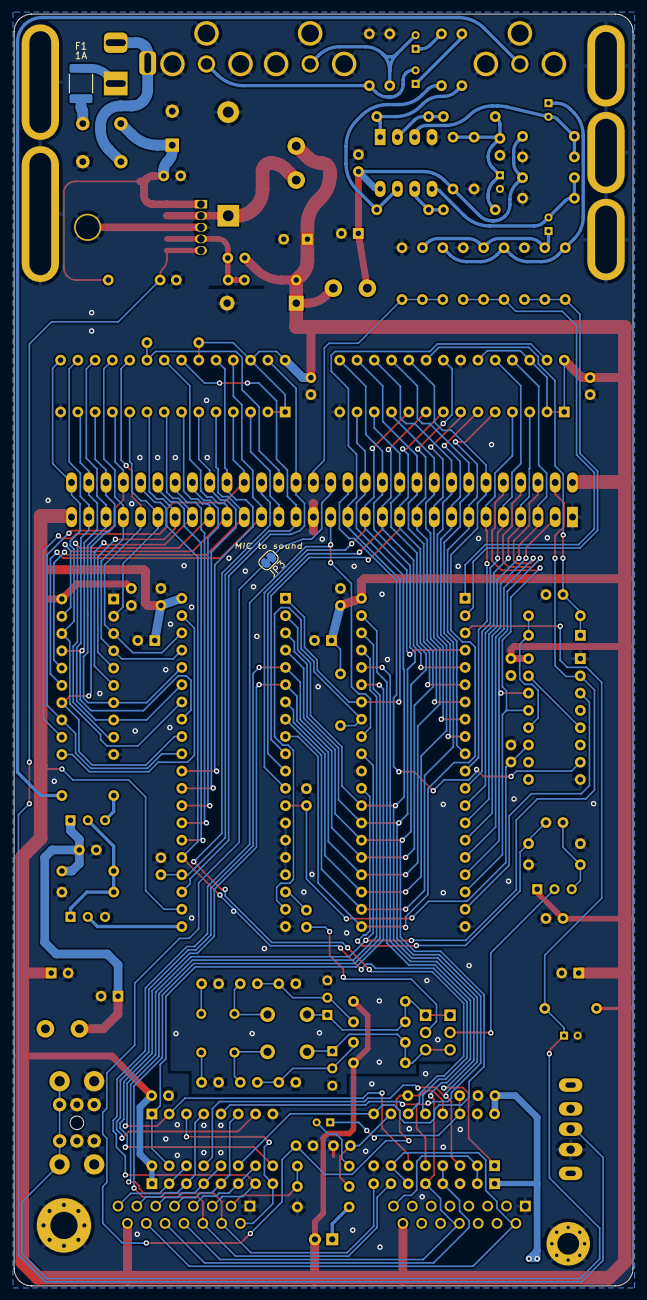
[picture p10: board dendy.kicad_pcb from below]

Board: 2 copper layers, 91.0 x 187.0 mm, 136 parts (2 on the bottom side), 127 nets.

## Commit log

2022-10-12 wip pcb rev.A
    [dendy.kicad_pcb, dendy.kicad_sch]
2024-06-01 pcb rev.A final version
    [dendy.kicad_sch]
2025-07-13 add pcb rev.A1
    [dendy.kicad_sch]
2025-07-13 add pcb rev.A errata
2025-07-13 add pcb rev.B
    [dendy.kicad_sch]
2025-07-15 add pcb rev.B1
    [dendy.kicad_sch]
